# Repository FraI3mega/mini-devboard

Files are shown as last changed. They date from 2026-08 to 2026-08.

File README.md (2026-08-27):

# Mini USB Devboard

<!--toc:start-->
- [Mini USB Devboard](#mini-usb-devboard)
  - [Features](#features)
  - [Schematic](#schematic)
  - [PCB](#pcb)
  - [Case](#case)
  - [Firmware](#firmware)
  - [BOM](#bom)
<!--toc:end-->

A little CH552G USB devboard, for quickly testing ideas.
I wanted a little board, with nice headers for quickly testing modules/ideas, as whenever i need one I can't find one.
That or I don't have the correct cable (shoutout to the RPi Pico's micro usb). It will also be my first time soldering smd, so that will be fun.

## Features

- 2 touch pads
- 2 LEDs
- pinouts for connecting external modules
- pads for I2C pullup resistors

## Schematic

[View in KiCanvas](https://kicanvas.org/?repo=https%3A%2F%2Fgithub.com%2FFraI3mega%2Fmini-devboard%2Ftree%2Fmain%2FPCB)
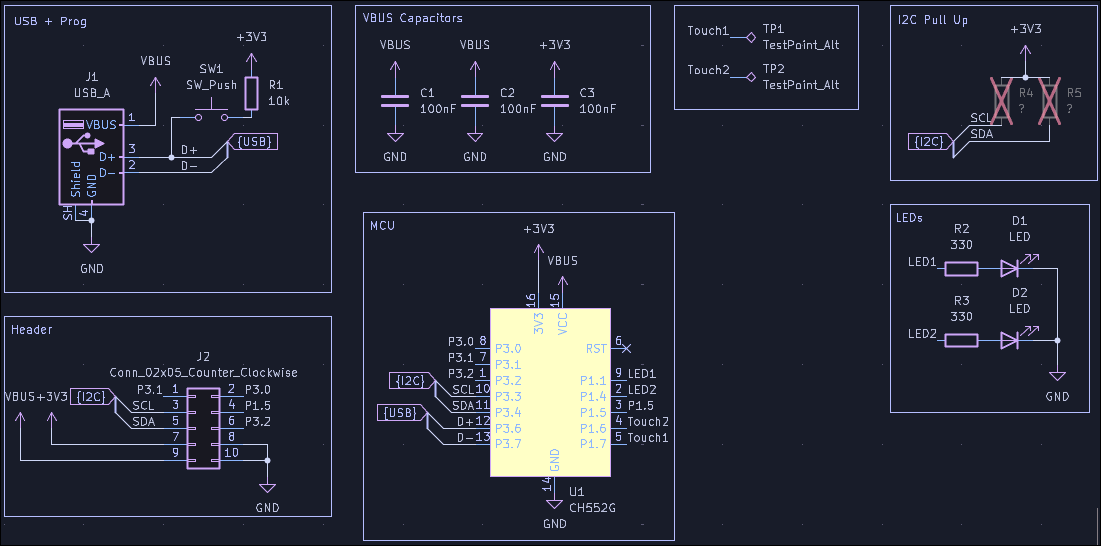
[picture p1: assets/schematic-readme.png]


## PCB

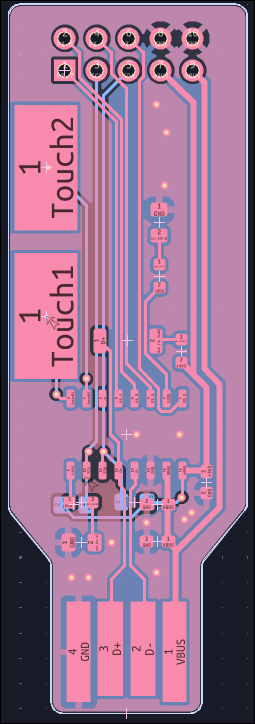
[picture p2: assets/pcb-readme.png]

The PCB itself is the USB jack.

## Case

[View in Onshape](https://cad.onshape.com/documents/f293c0d155c2cb71ac8b7631/w/f75f334043fc1f5ab23cc771/e/bf8eef9c1f6021e41664814e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)
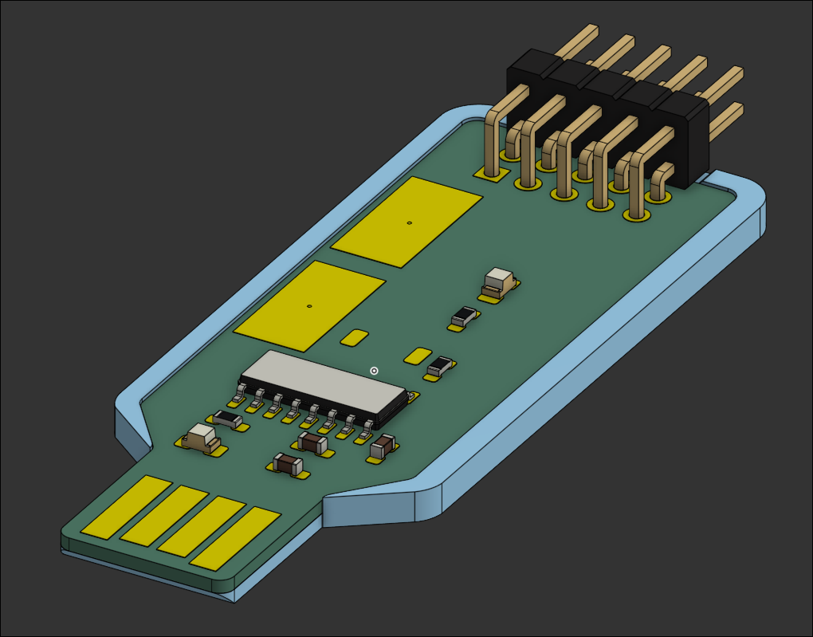
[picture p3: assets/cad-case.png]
 
The PCB is press fit into the case, which adds the necessary thickness for the USB jack.

## Firmware

The included firmware blinks one led, and lights the other one with the touchpad closer to the USB jack.

## BOM

| Name | Qnt | Link | Price |
|---|---|--- |---|
|PCB | 5 | jlcpcb.com | 18.70 USD (PCB) + 1.50 USD (Shipping) + 8.92 USD (Taxes) = 29.12 USD |
| OF-SMD2012R Red LED | 2 | [https://www.tme.eu/pl/details/of-smd2012r/diody-led-smd-kolorowe/optoflash/] | 2.78 PLN |
| TSW-105-08-F-D-RA Pins | 1 | [https://www.tme.eu/pl/details/tsw-105-08-f-d-ra/listwy-i-gniazda-kolkowe/samtec/] | 3.96 PLN |
| CH552G | 1 | [https://pl.aliexpress.com/item/1005006904524984.html] | 34.93 (item + taxes) PLN |
| CL10B104KO8NNNL 100nF cap | 3 | [https://www.tme.eu/pl/details/cl10b104ko8nnnl/kondensatory-mlcc-smd/samsung/] | 0.91 PLN |
| WR06X3300FTL 330 Ohm Resistor | 2 | [https://www.tme.eu/pl/details/wr06x3300ftl/rezystory-smd/walsin/] | 0.47 PLN |
| WR06X103JTL 10k Resistor | 1 | [https://www.tme.eu/pl/details/wr06x103jtl/rezystory-smd/walsin/wr06x103-jtl/] | 0.69 PLN |
| TS-1088-AR02016 Switch | 1 | [https://pl.aliexpress.com/item/1005011940516004.html] | 21.31 (item+ taxes) PLN |
| TME Delivery | 1 | - | 17.10 PLN |

Total PLN price: 25.91 (TME) + 34.93 + 21.31 = 82.15 PLN ≈ 23 USD
Total USD: 52.12

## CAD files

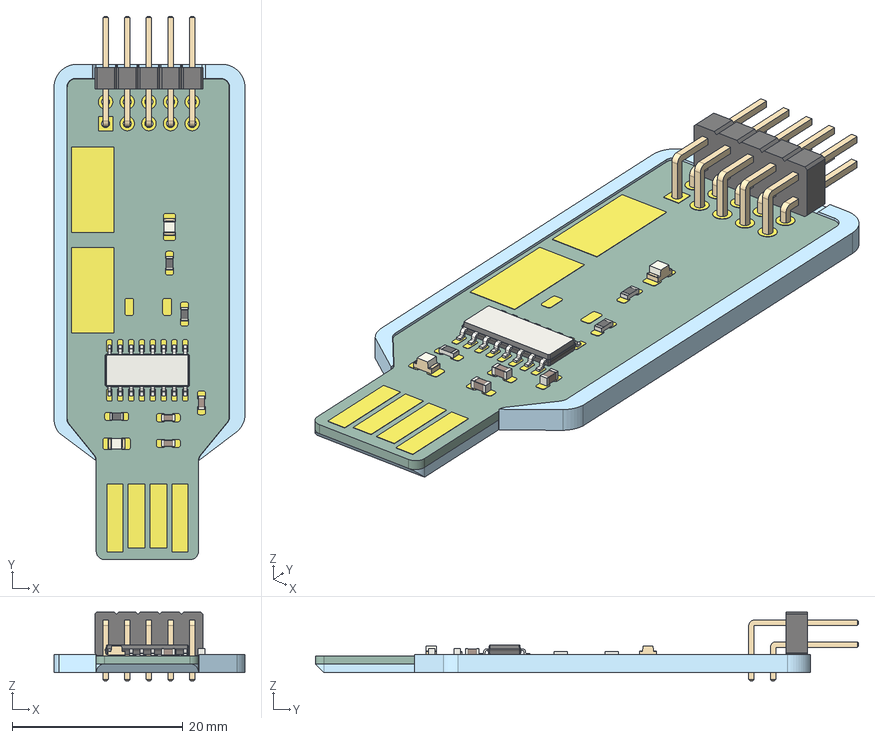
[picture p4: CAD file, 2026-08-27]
CAD/mini-devboard.step
22.4 x 63.7 x 8.08 mm
PinHeader_2x05_P254mm_Horizontal
mini-devboard-unsaved-export-j24gy2_copper x 54
R_0603_1608Metric_1
LED_0805_2012Metric
R_0603_1608Metric_2
SOP-16_3.9x9.9mm_P1.27mm
R_0805_2012Metric
C_0603_1608Metric
LED_0805_2012Metric_1
R_0603_1608Metric
C_0603_1608Metric_2
mini-devboard-unsaved-export-j24gy2_PCB
R_0805_2012Metric_1
C_0603_1608Metric_1

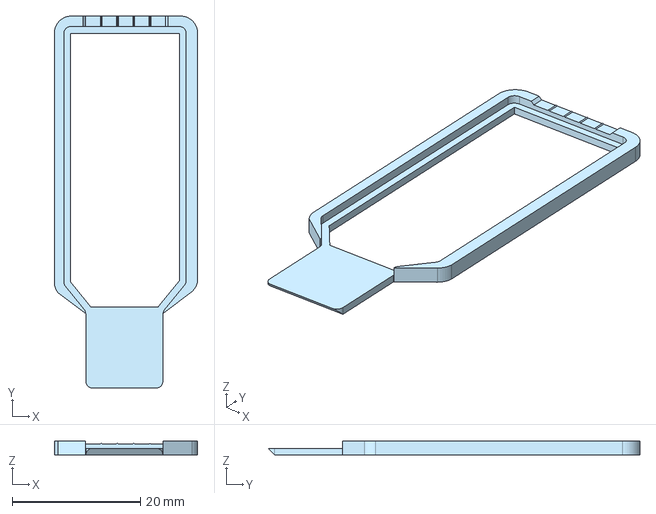
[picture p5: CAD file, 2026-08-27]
Production/Case.step
22.4 x 58.1 x 2.11 mm

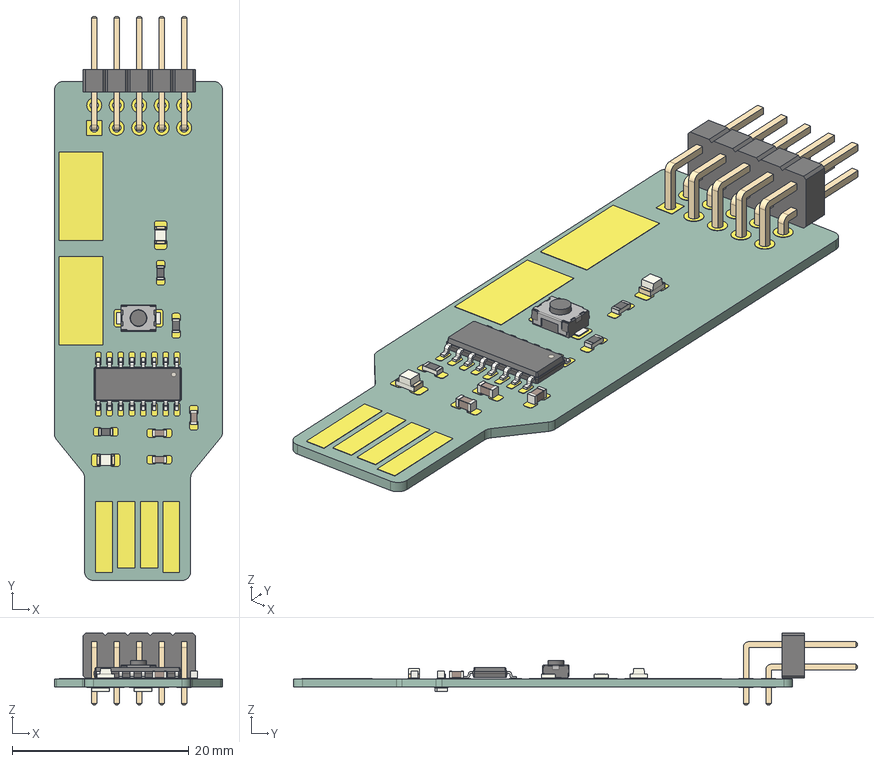
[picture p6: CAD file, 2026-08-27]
CAD/PCB.step
19.0 x 63.7 x 8.08 mm
R_0603_1608Metric x 3
PinHeader_2x05_P254mm_Horizontal
LED_0805_2012Metric x 2
SOP-16_3.9x9.9mm_P1.27mm
SW_SPST_TS-1088-xR020
C_0603_1608Metric x 3
R_0805_2012Metric x 2
mini-devboard-unsaved-export-j24gy2_copper
mini-devboard-unsaved-export-j24gy2_PCB

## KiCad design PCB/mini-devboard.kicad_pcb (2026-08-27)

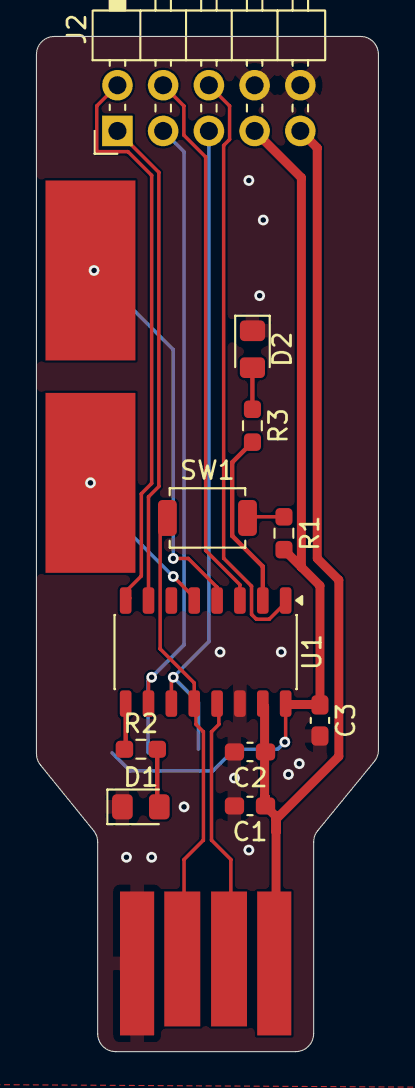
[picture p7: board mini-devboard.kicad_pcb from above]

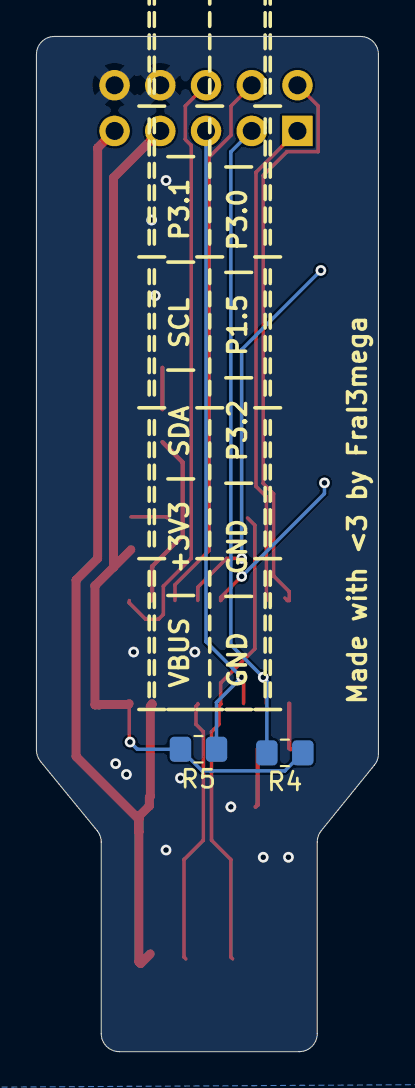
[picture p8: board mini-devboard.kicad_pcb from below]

Board: 2 copper layers, 19.0 x 56.4 mm, 16 parts (2 on the bottom side), 18 nets.

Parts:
C1, C2, C3: 100nF; C_0603_1608Metric_Pad1.08x0.95mm_HandSolder
D1, D2: LED; LED_0805_2012Metric_Pad1.15x1.40mm_HandSolder
J1: USB_A; USB-A
J2: Conn_02x05_Counter_Clockwise; PinHeader_2x05_P2.54mm_Horizontal
R1: 10k; R_0603_1608Metric_Pad0.98x0.95mm_HandSolder
R2, R3: 330; R_0603_1608Metric_Pad0.98x0.95mm_HandSolder
R4, R5: ?; R_0805_2012Metric_Pad1.20x1.40mm_HandSolder
SW1: SW_Push; SW_SPST_TS-1088-xR020
TP1, TP2: TestPoint_Alt; TestPoint_Pad_4.0x4.0mm
U1: CH552G; JEITA_SOIC-16_3.9x9.9mm_P1.27mm

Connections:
+3V3: C3.1, J2.7, R1.2, R4.2, R5.2, U1.16 (3V3)
/LED1: R2.1, U1.9 (P1.1)
/LED2: R3.2, U1.2 (P1.4)
/P1.5: J2.4, U1.3 (P1.5)
/P3.0: J2.2, U1.8 (P3.0)
/P3.1: J2.1, U1.7 (P3.1)
/P3.2: J2.6, U1.1 (P3.2)
/Touch1: TP1.1 (1_1), U1.5 (P1.7)
/Touch2: TP2.1 (1_1), U1.4 (P1.6)
D+: J1.3 (D+), SW1.1, U1.12 (P3.6)
D-: J1.2 (D-), U1.13 (P3.7)
GND: C1.2, C2.2, C3.2, D1.1 (K), D2.1 (K), J1.4 (GND), J2.8, J2.10, U1.14 (GND)
unnamed: D1.2 (A), R2.2
unnamed: D2.2 (A), R3.1
unnamed: R1.1, SW1.2
SCL: J2.3, R4.1, U1.10 (P3.3)
SDA: J2.5, R5.1, U1.11 (P3.4)
VBUS: C1.1, C2.1, J1.1 (VBUS), J2.9, U1.15 (VCC)

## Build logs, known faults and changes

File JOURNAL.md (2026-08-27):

# Mini USB Devboard

<!--toc:start-->
- [Mini USB Devboard](#mini-usb-devboard)
  - [26/08/2026: Made the Schematic](#26082026-made-the-schematic)
  - [26/08/2026: Finished the PCB](#26082026-finished-the-pcb)
  - [27/08/2026: A Simple Case](#27082026-a-simple-case)
  - [27/08/2026: Finding Components and a Better README](#27082026-finding-components-and-a-better-readme)
<!--toc:end-->

A little CH552G USB Devboard, for quickly testing ideas.

Total hours: 8h

## 26/08/2026: Made the Schematic

Time Spent: 2h
Made the schematic for the board. The guide on the ysws was really helpful.
Still not sure what to do with the two leftover pins. Might just add more LEDs.
I tried out the bus feature in KiCad, it definitely helps once you have more than of bus in the project.
Definitely need to add pads for I2C pull-up resistors.
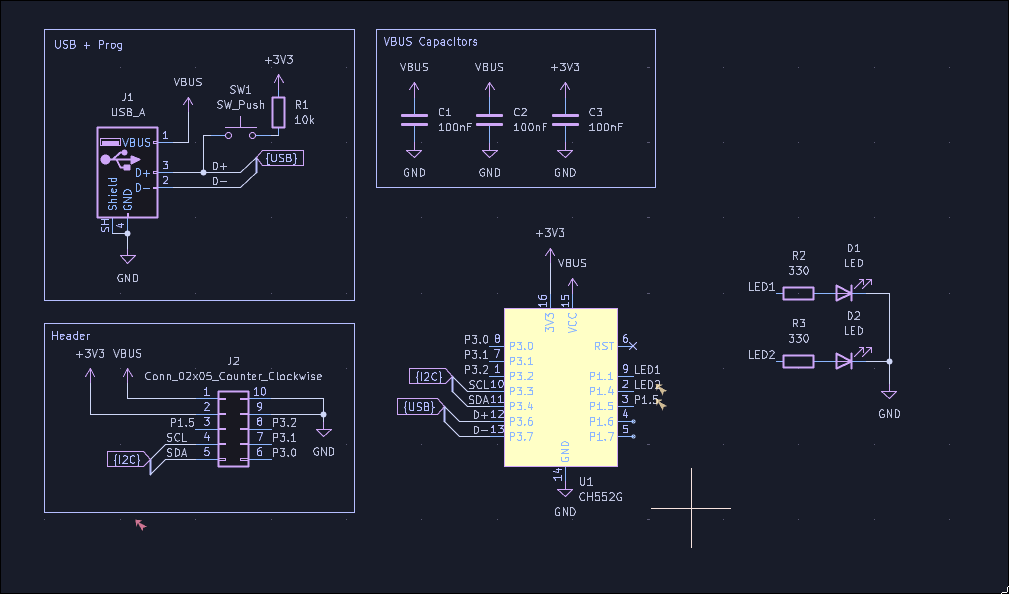
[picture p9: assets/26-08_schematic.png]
A screenshot showing the schematic


## 26/08/2026: Finished the PCB

Time Spent: 2h
Added some finishing touches to the schematic ( and the I2C stuff)
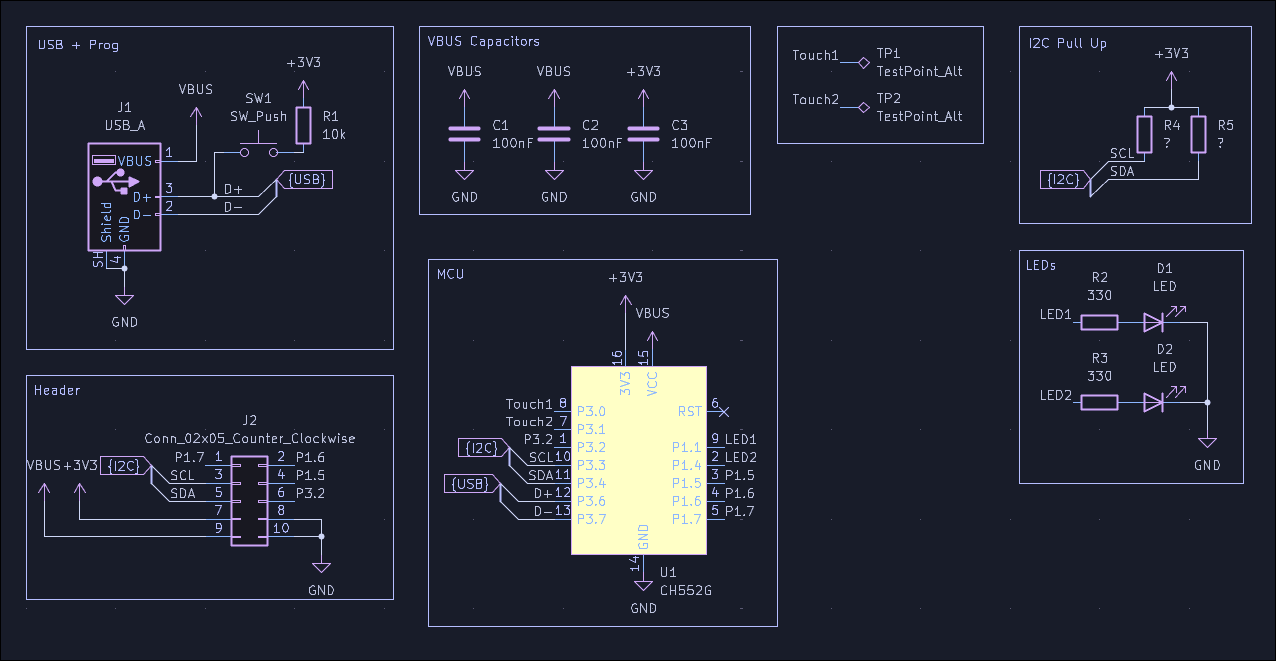
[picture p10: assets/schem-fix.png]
A screenshot showing the scheamtic after improvements

Also made the PCB, using it as the USB connector.

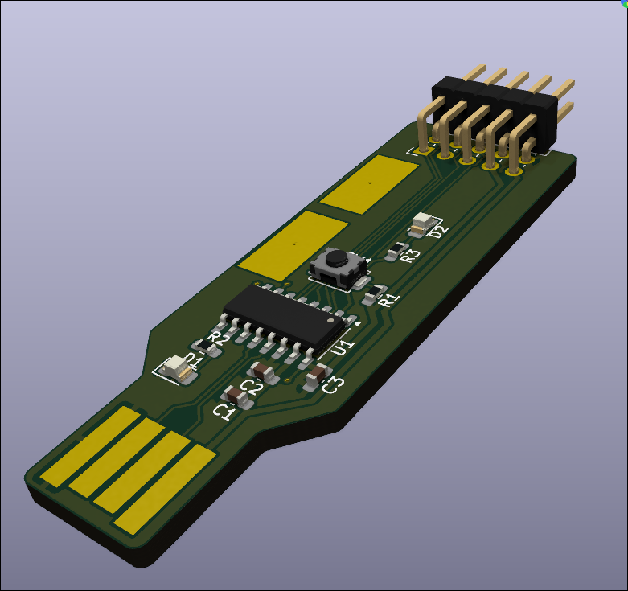
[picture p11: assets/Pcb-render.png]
A render of the pcb with all the components

It has 2 LEDs on it, as well as two touch pads for inputs
All the other pins are available on the header with a nice cheat sheet on the underside.

## 27/08/2026: A Simple Case

Time Spent: 1h
I didn't want to obscure the underside of the pcb, since I put a pin cheatsheet there, so I went with an open-bottom case
The case is supposed to be snap fit.


## 27/08/2026: Finding Components and a Better README

Time Spent: 2h
Finally got and found all the components for the build.
With the new EU tariffs, china is not feasible for small quantities. Thankfully TME had most of the components.
It's my first time picking components out, so I hope they will all be good.
Also got to work on filling out the README a bit more.

## 28/08/2026: Quick Firmware
Time Spent: 1h
Just realised that I had used the wrong pins for the the touch pads, should be correct now
Modified the blink code to add a quick touch test. Have to work on it.
I'm honestly tired and just want to be done with this

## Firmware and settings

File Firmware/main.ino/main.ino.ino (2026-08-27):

#include <TouchKey.h>

#define LED_1 11
#define LED_2 14



// the setup function runs once when you press reset or power the board
void setup() {
  // initialize digital pin LED_BUILTIN as an output.
  pinMode(LED_1, OUTPUT);
  pinMode(LED_2, OUTPUT);
  TouchKey_begin((1 << 5));  //Enable TIN5(P1.7)
}

// the loop function runs over and over again forever
void loop() {
  digitalWrite(LED_1, HIGH);  // turn the LED on (HIGH is the voltage level)
  delay(1000);                // wait for a second
  digitalWrite(LED_1, LOW);   // turn the LED off by making the voltage LOW
  delay(1000);                // wait for a second
  TouchKey_Process();
  uint8_t touchResult = TouchKey_Get();
  if (touchResult) {
    digitalWrite(LED_2, HIGH);
  } else {
    digitalWrite(LED_2, LOW);
  }
}

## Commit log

2026-08-26 some starting schematic and PCB
    [mini-devboard.kicad_pcb, mini-devboard.kicad_sch]
2026-08-26 make the pcb
    [mini-devboard.kicad_pcb, mini-devboard.kicad_sch]
2026-08-27 finishing touches
    [mini-devboard.kicad_pcb]
2026-08-27 add PCB cad
    [PCB.step]
2026-08-27 changes i'm so tired
    [mini-devboard.kicad_pcb, mini-devboard.kicad_sch]
